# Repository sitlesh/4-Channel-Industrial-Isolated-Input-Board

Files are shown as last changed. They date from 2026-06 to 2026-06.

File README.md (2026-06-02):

# 4-Channel Industrial Isolated Digital Input Board ⚡🏭

This repository contains the complete hardware design, production-ready Gerber files, and simulation models for a professional 4-channel isolated digital input card. It safely interfaces 24V industrial signals (from PLCs, proximity sensors, pushbuttons) with sensitive 3.3V/5V microcontrollers (like STM32, Arduino, or ESP32).

---

## 📸 Visuals & Renders

### 3D View of the Board
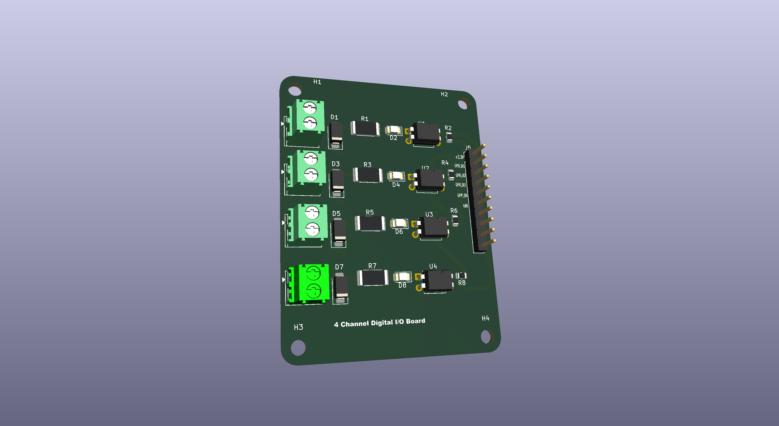
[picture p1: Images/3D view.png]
3D View


### Top Silkscreen & Track Routing
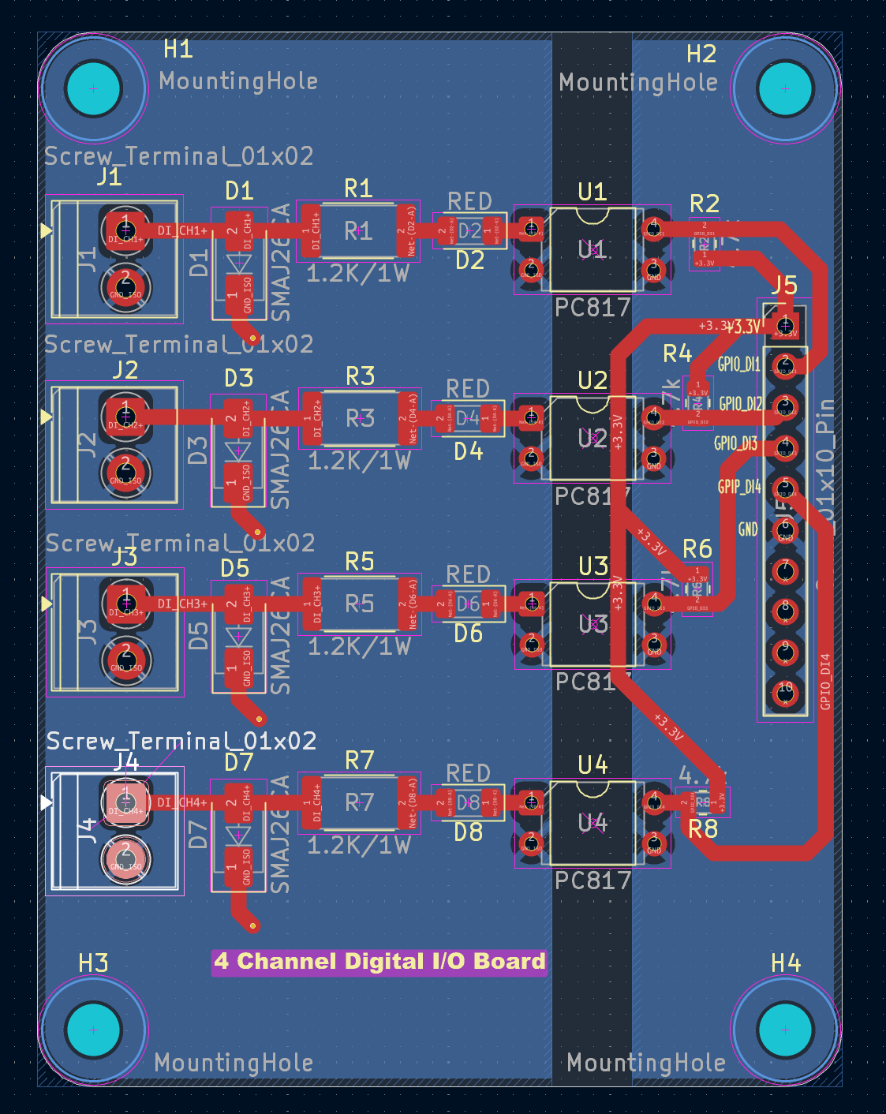
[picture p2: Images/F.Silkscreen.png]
PCB Layout


### Gerber Production Preview
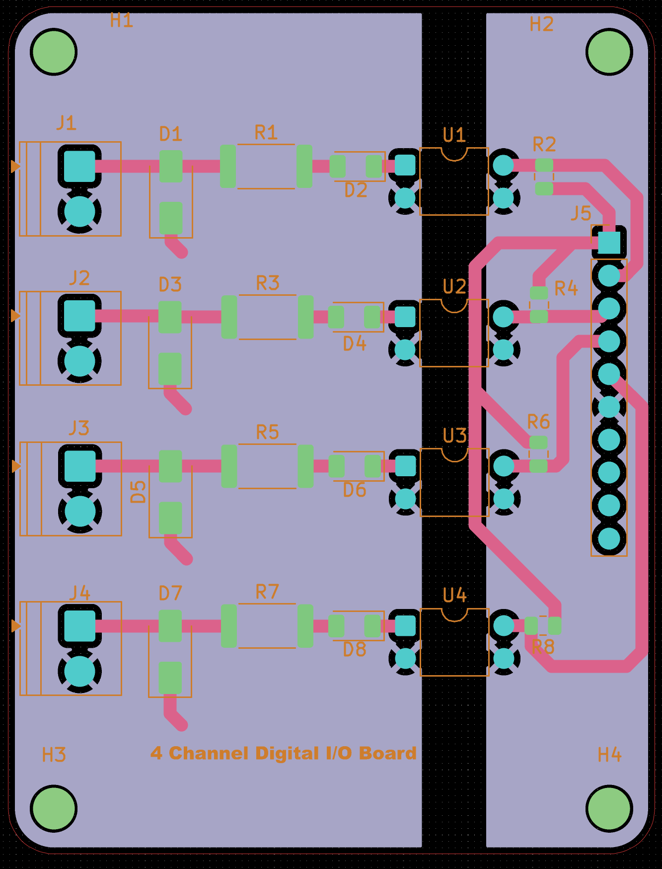
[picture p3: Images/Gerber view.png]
Gerber View


---

## 📌 Project Overview
Industrial environments are full of electrical noise, voltage surges, and ground loops. This board provides complete galvanic isolation and transient protection for 4 independent input channels.

### Key Specifications:
- **Input Voltage:** 24V DC nominal (Field Side)
- **Output Logic:** 3.3V Active-Low (Logic Side)
- **PCB Dimensions:** 65mm x 50mm (2-Layer Board)
- **Software Used:** KiCad 8.0 (PCB Design) & LTspice (Circuit Simulation)

---

## 🛠️ Hardware Features & Architecture

### 1. Galvanic Isolation
- Uses **PC817 Optocouplers** to completely separate the 24V Field Circuit from the 3.3V Logic Circuit.
- Features a strict **5mm physical isolation trench** (Creepage distance) across the copper layers to ensure no electrical arcing occurs.

### 2. Circuit Protection
- **SMAJ24CA Transient Voltage Suppressor (TVS) Diodes** are placed directly at the input connectors to clamp high-voltage spikes and surges.
- Input current limiting via large **2512-packaged 1.2kΩ resistors** to safely handle thermal dissipation.

### 3. Visual Indicators
- Each channel includes a low-power **1206 status LED** for instant visual debugging on the factory floor.

---

## 📊 LTspice Simulation & Logic
Before layout execution, the circuit logic was thoroughly verified using **LTspice Transient Analysis**. 
- **Inverted Logic:** When a 24V input is detected (HIGH), the optocoupler transistor pulls the MCU pin to 0V (LOW). When the input is disconnected (LOW), the 4.7kΩ pull-up resistor pulls the pin to 3.3V (HIGH).

---

## 📁 Repository File Guide
*Click on the links below to view the source files directly inside GitHub:*

* 📄 **[Schematic File (.kicad_sch)](Industrial%204-Channel%20Isolated%20Digital%20Input%20Output%20Board.kicad_sch)** - Circuit schematics, component ratings, and connections.
* 🎛️ **[PCB Layout File (.kicad_pcb)](Industrial%204-Channel%20Isolated%20Digital%20Input%20Output%20Board.kicad_pcb)** - 2-layer track routing, ground planes, and component placements.
* 📦 **[Production Gerbers (.zip)](Gerbers.zip)** - Manufacture-ready fabrication files (Gerber + Drill data).
* 📁 **[Images Directory](/Images)** - Folder containing the 3D renders and layouts used in this readme.

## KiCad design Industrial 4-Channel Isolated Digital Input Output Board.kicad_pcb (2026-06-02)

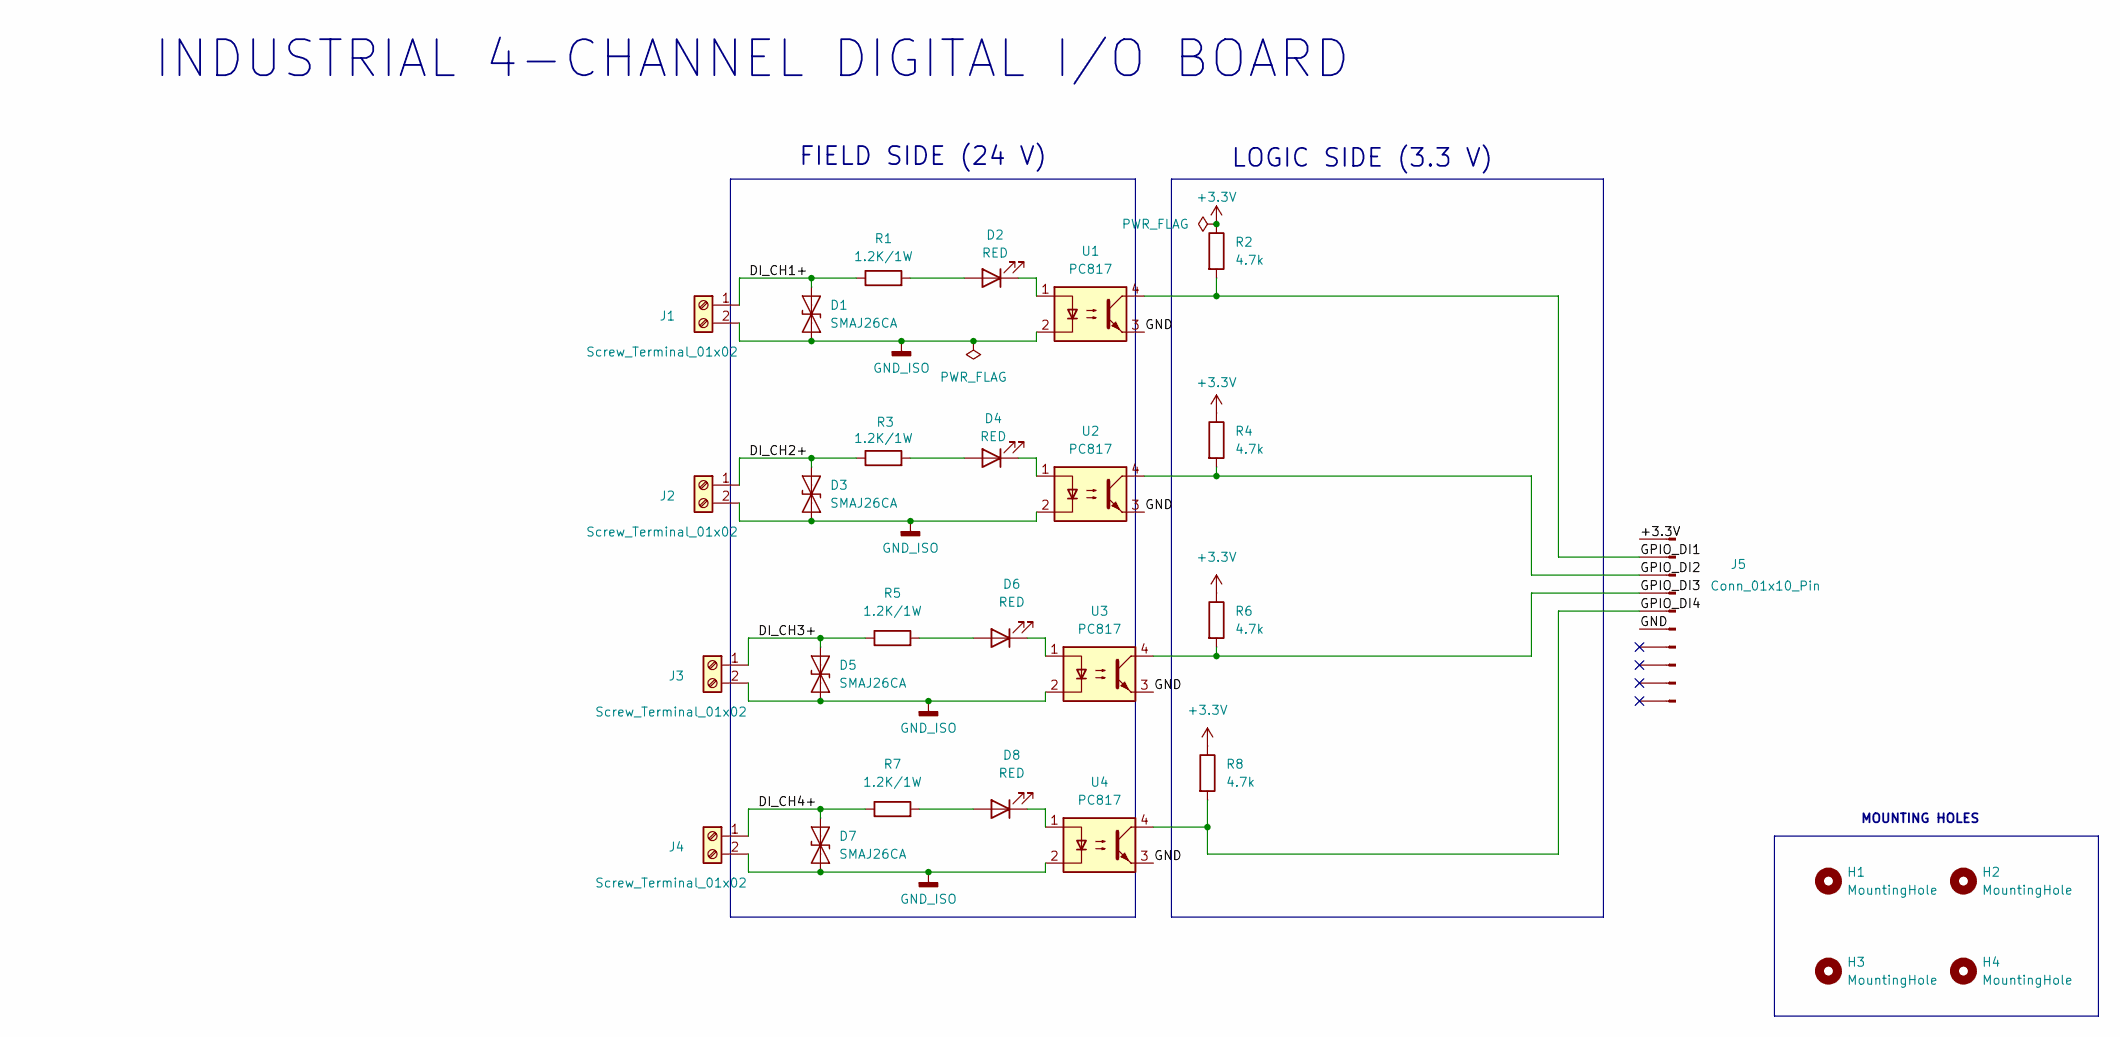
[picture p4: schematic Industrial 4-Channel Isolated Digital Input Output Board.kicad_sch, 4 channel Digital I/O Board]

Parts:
D1, D3, D5, D7: SMAJ26CA; D_SMA
D2, D4, D6, D8: RED; LED_1206_3216Metric
H1, H2, H3, H4: MountingHole; MountingHole_3.2mm_M3
J1, J2, J3, J4: Screw_Terminal_01x02; TerminalBlock_Phoenix_PT-1,5-2-3.5-H_1x02_P3.50mm_Horizontal
J5: Conn_01x10_Pin; PinHeader_1x10_P2.54mm_Vertical
R1, R3, R5, R7: 1.2K/1W; R_2512_6332Metric
R2, R4, R6, R8: 4.7k; R_0805_2012Metric
U1, U2, U3, U4: PC817; DIP-4_W7.62mm

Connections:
+3.3V: J5.1, R2.1, R4.1, R6.1, R8.1
/DI_CH1+: D1.2 (A2), J1.1, R1.1
/DI_CH2+: D3.2 (A2), J2.1, R3.1
/DI_CH3+: D5.2 (A2), J3.1, R5.1
/DI_CH4+: D7.2 (A2), J4.1, R7.1
/GND: J5.6, U1.3, U2.3, U3.3, U4.3
/GPIO_DI1: J5.2, R2.2, U1.4
/GPIO_DI2: J5.3, R4.2, U2.4
/GPIO_DI3: J5.4, R6.2, U3.4
/GPIO_DI4: J5.5, R8.2, U4.4
GND_ISO: D1.1 (A1), D3.1 (A1), D5.1 (A1), D7.1 (A1), J1.2, J2.2, J3.2, J4.2, U1.2, U2.2, U3.2, U4.2
unnamed: D2.2 (A), R1.2
unnamed: D2.1 (K), U1.1
unnamed: D4.2 (A), R3.2
unnamed: D4.1 (K), U2.1
unnamed: D6.2 (A), R5.2
unnamed: D6.1 (K), U3.1
unnamed: D8.2 (A), R7.2
unnamed: D8.1 (K), U4.1

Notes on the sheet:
FIELD SIDE (24 V)
MOUNTING HOLES
LOGIC SIDE (3.3 V)
INDUSTRIAL 4-CHANNEL DIGITAL I/O BOARD

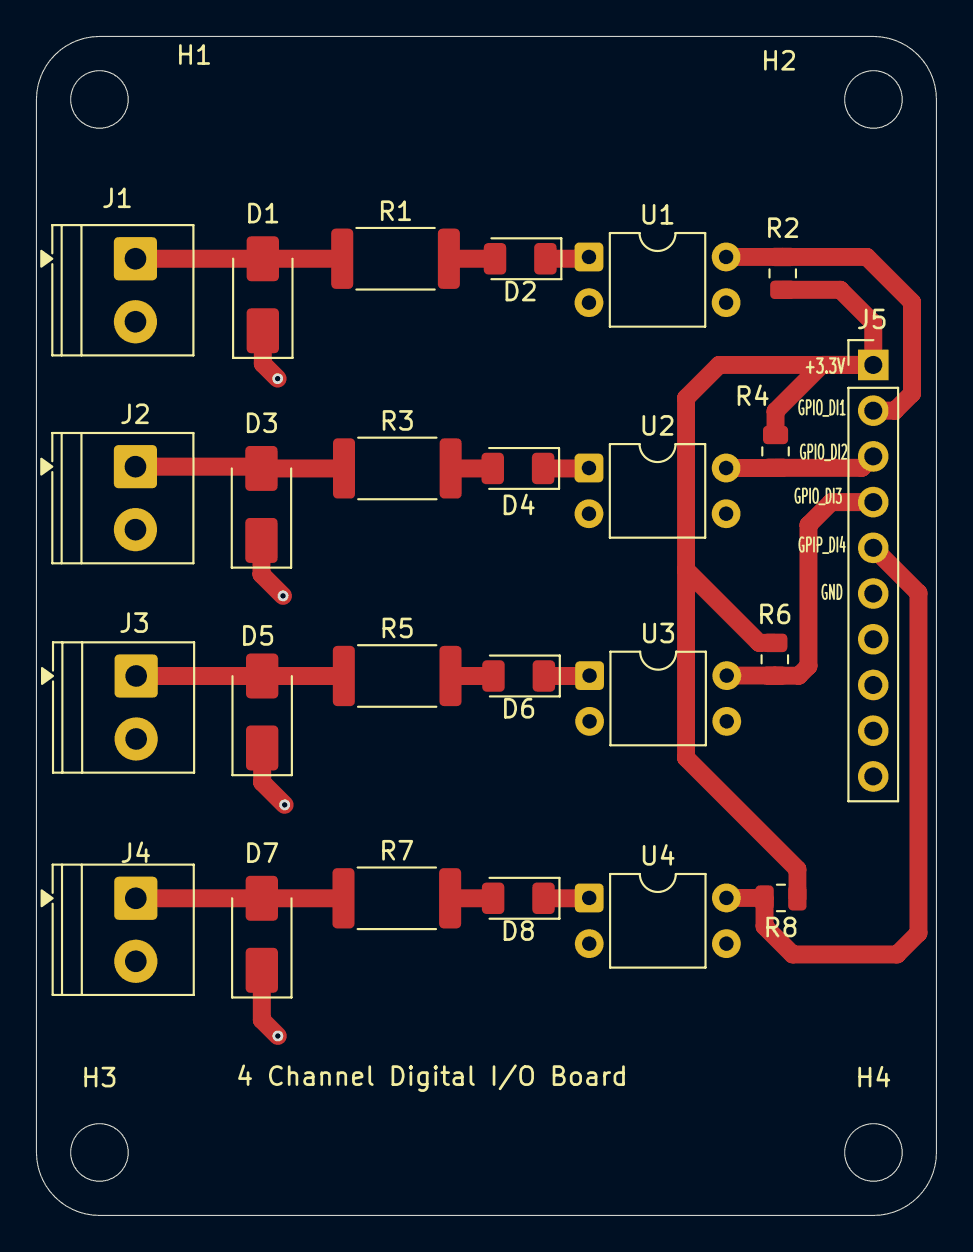
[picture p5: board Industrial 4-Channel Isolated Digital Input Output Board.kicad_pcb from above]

Board: 2 copper layers, 50.0 x 65.5 mm, 29 parts (0 on the bottom side), 19 nets.

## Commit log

2026-06-02 Rename Industrial 4-Channel Isolated Digital Input Output Board.png to 3D view
2026-06-02 Rename Screenshot (49).png to F.Silkscreen.png
2026-06-02 Rename Screenshot (50).png to Gerber view.png
